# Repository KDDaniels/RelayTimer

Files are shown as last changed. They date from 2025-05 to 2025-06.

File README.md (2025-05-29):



# Relay Timer

Simple timer with a two button interface and LCD screen to show the time remaining. Intended to control a relay but could be used for anything else really.

# Dependencies

I couldn't find it on the PlatformIO library explorer, but this project requires the **[LiquidCrystal_attiny](https://github.com/platisd/ATtiny85-LCD-library/tree/master)** library.

## Features:
- Adjustable time, goes up to 9:59:59 max by default but can be adjusted
- Timer is pausable whenever needed
- Can easily reset the timer while paused or before starting

## Wiring

Intended for an **ATtiny85**, this could definitely be ported to other microcontrollers if needed. Will need slight adjustment due to the direct port register manipulation though.

- NC = No connection
- FB = Function button
- TB = Toggle button
- SCL goes to SCL
- SDA goes to SDA
- Relay goes to a transistor (or straight to a relay if you're feeling bold (don't do that))

```
             ATtiny85
             __   __
 NC <- PB5 =|1 *-* 8|= VCC <- +5v
 FB <- PB3 =|2     7|= PB2 -> SCL
 TB <- PB4 =|3     6|= PB1 -> Relay
GND <- GND =|4_____5|= PB0 -> SDA

```

# Hardware
- ATtiny85 or another microcontroller (will require modification)
- LCD with I<sup>2</sup>C support (I'm using a 1602 screen with a PCF8574 board)
- A relay module
- Two buttons
- A single NPN transistor (I'm using a 2N2222)
- A few resistors (2 4.7kOhm and 5 1kOhm)

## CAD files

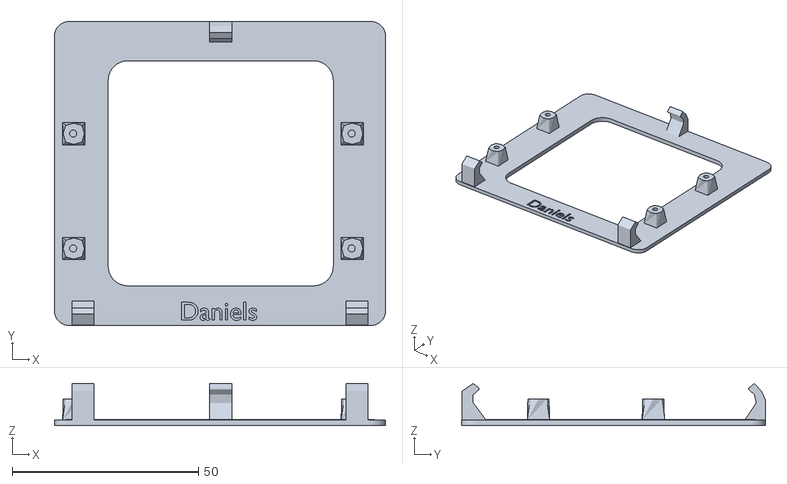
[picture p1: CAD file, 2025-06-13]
assets/RelayTimer_support.stl
88.9 x 81.7 x 11.3

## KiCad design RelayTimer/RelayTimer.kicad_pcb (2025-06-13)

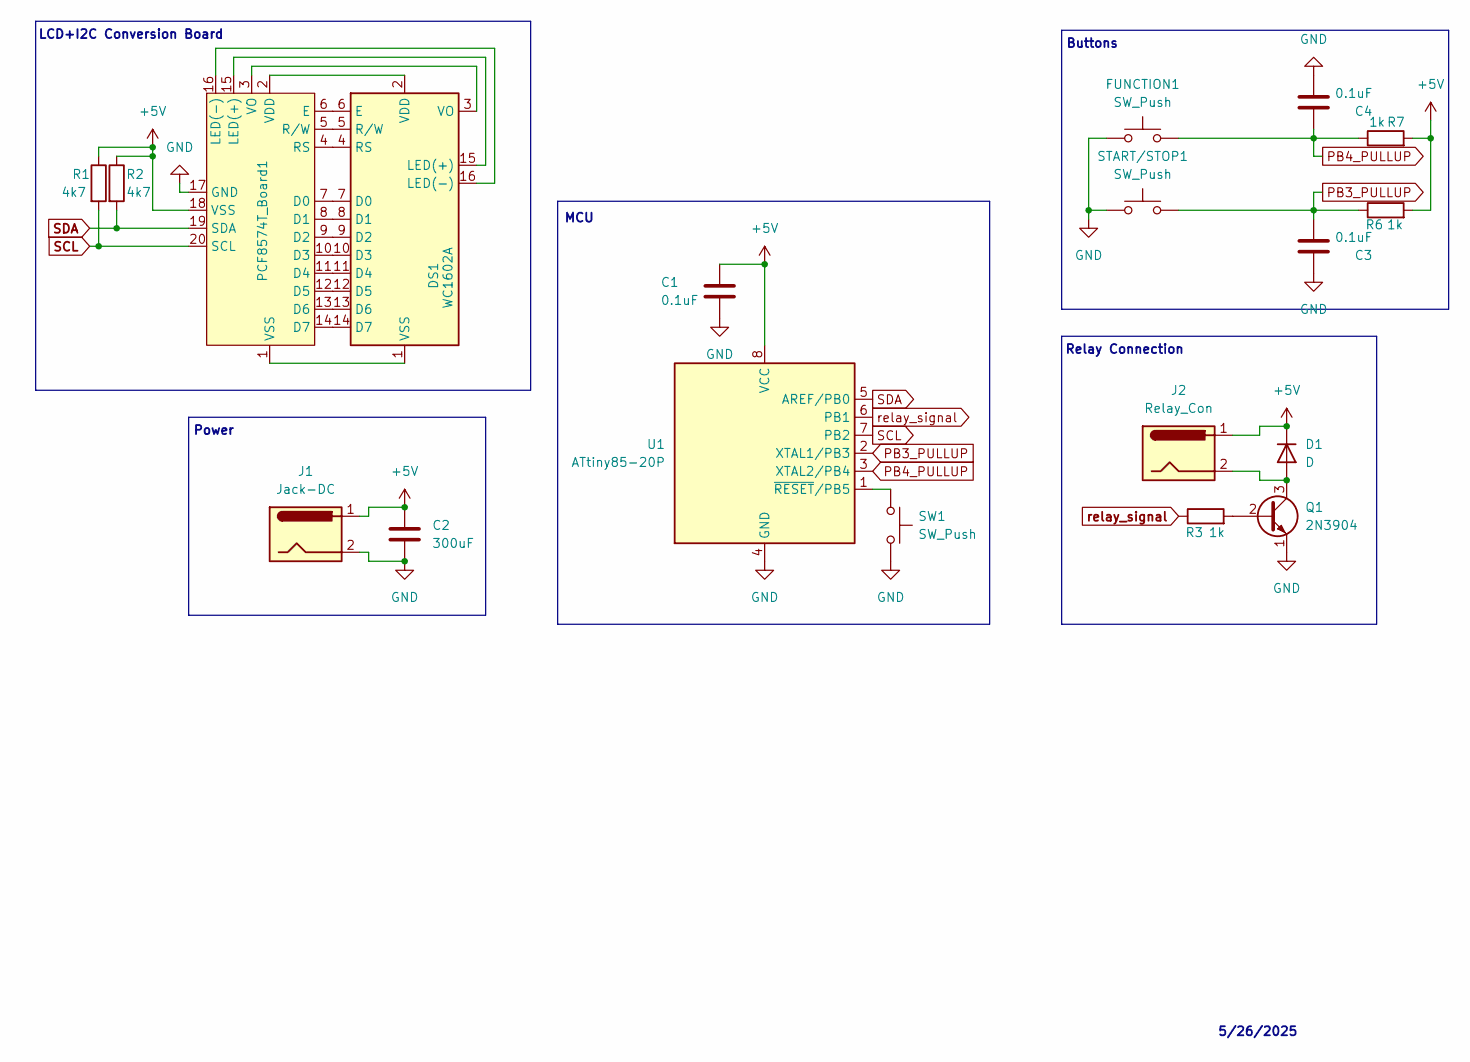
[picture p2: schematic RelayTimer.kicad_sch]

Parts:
C1, C3, C4: 0.1uF; C_Disc_D3.0mm_W1.6mm_P2.50mm
C2: 300uF; C_Radial_D10.0mm_H12.5mm_P5.00mm
D1: D; D_DO-41_SOD81_P2.54mm_Vertical_KathodeUp
DS1: WC1602A
FUNCTION1: SW_Push; SW_PUSH-12mm
J1: Jack-DC; BarrelJack_GCT_DCJ200-10-A_Horizontal
J2: Relay_Con; BarrelJack_GCT_DCJ200-10-A_Horizontal
PCF8574T_Board1: PCF8574T
Q1: 2N3904; TO-92
R1, R2: 4k7; R_Axial_DIN0204_L3.6mm_D1.6mm_P2.54mm_Vertical
R3: 1k; R_Axial_DIN0204_L3.6mm_D1.6mm_P2.54mm_Vertical
R6, R7: 1k; R_Axial_DIN0204_L3.6mm_D1.6mm_P7.62mm_Horizontal
START/STOP1: SW_Push; SW_PUSH-12mm
SW1: SW_Push; SW_PUSH_6mm
U1: ATtiny85-20P; DIP-8_W7.62mm

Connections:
+5V: C1.2, C2.1, D1.1 (K), J1.1, J2.1, PCF8574T_Board1.18 (VSS), R1.1, R2.1, R6.2, R7.2, U1.8 (VCC)
GND: C1.1, C2.2, C3.2, C4.1, FUNCTION1.1, J1.2, PCF8574T_Board1.17 (GND), Q1.1 (E), START/STOP1.1, SW1.2, U1.4 (GND)
unnamed: D1.2 (A), J2.2, Q1.3 (C)
unnamed: DS1.7 (D0), PCF8574T_Board1.7 (D0)
unnamed: DS1.8 (D1), PCF8574T_Board1.8 (D1)
unnamed: DS1.9 (D2), PCF8574T_Board1.9 (D2)
unnamed: DS1.10 (D3), PCF8574T_Board1.10 (D3)
unnamed: DS1.11 (D4), PCF8574T_Board1.11 (D4)
unnamed: DS1.12 (D5), PCF8574T_Board1.12 (D5)
unnamed: DS1.13 (D6), PCF8574T_Board1.13 (D6)
unnamed: DS1.14 (D7), PCF8574T_Board1.14 (D7)
unnamed: DS1.6 (E), PCF8574T_Board1.6 (E)
unnamed: DS1.15 (LED(+)), PCF8574T_Board1.15 (LED(+))
unnamed: DS1.16 (LED(-)), PCF8574T_Board1.16 (LED(-))
unnamed: DS1.4 (RS), PCF8574T_Board1.4 (RS)
unnamed: DS1.5 (R/W), PCF8574T_Board1.5 (R/W)
unnamed: DS1.2 (VDD), PCF8574T_Board1.2 (VDD)
unnamed: DS1.3 (VO), PCF8574T_Board1.3 (VO)
unnamed: DS1.1 (VSS), PCF8574T_Board1.1 (VSS)
unnamed: Q1.2 (B), R3.2
unnamed: SW1.1, U1.1 (~RESET/PB5)
PB3_PULLUP: C3.1, R6.1, START/STOP1.2, U1.2 (XTAL1/PB3)
PB4_PULLUP: C4.2, FUNCTION1.2, R7.1, U1.3 (XTAL2/PB4)
SCL: PCF8574T_Board1.20 (SCL), R1.2, U1.7 (PB2)
SDA: PCF8574T_Board1.19 (SDA), R2.2, U1.5 (AREF/PB0)
relay_signal: R3.1, U1.6 (PB1)

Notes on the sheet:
Relay Connection
Power
5/26/2025
Buttons
MCU
LCD+I2C Conversion Board

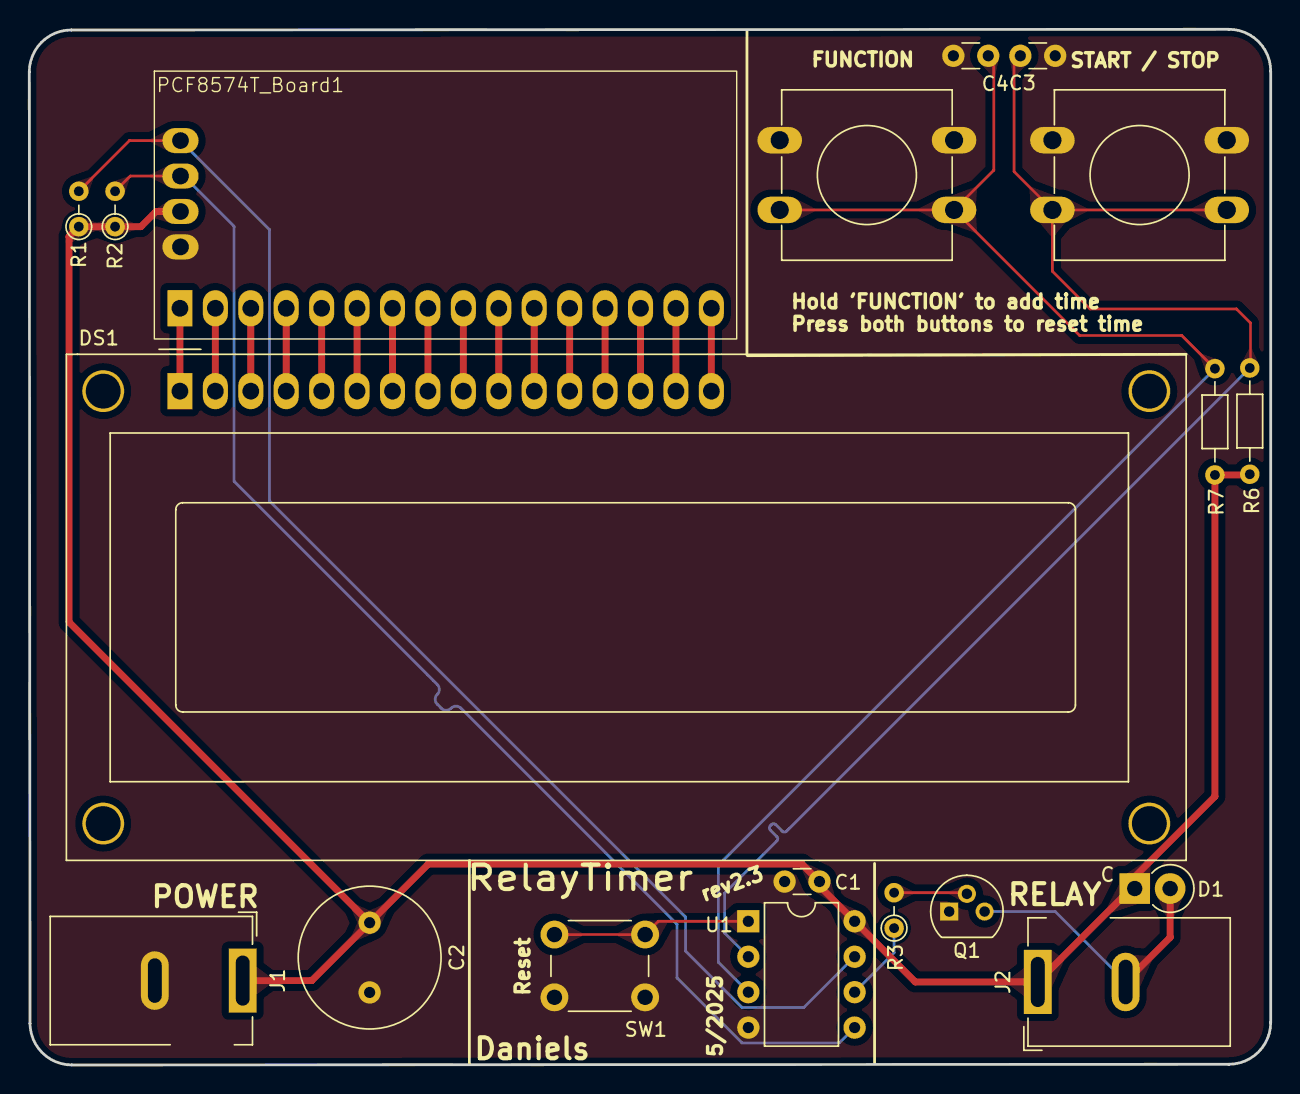
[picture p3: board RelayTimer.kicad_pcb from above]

Board: 2 copper layers, 89.0 x 74.3 mm, 19 parts (0 on the bottom side), 26 nets.

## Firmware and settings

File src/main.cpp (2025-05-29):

/*
RelayTimer is a simple interactive timer to control a relay.
Copyright (C) 2025 Kendall Daniels

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
You should have received a copy of the GNU General Public License
along with this program.  If not, see <https://www.gnu.org/licenses/>.
*/

#include "buttons.h"
#include "display.h"
#include "relay.h"
#include "timer.h"

#define RELAY_PIN PB1
#define FUNC_PIN PB3
#define TOGGLE_PIN PB4

const uint32_t TIMER_INCREMENT = 5000;

bool isRunning = false;

void setup()
{
  SCREEN::init();
  RELAY::init(RELAY_PIN);
  BUTTONS::init(FUNC_PIN, TOGGLE_PIN);

  SCREEN::print("Select time            ", 0, 0);
  SCREEN::print(TIMER::getTimeRemainingFormatted(), 0, 1);
}

void loop()
{
  TIMER::update();
  if (isRunning == true)
  {
    if (!TIMER::paused())
    {
      // Updates the time if not paused
      TIMER::updateTimeRemaining();
      SCREEN::print("Time remaining:     ", 0, 0);
      SCREEN::print(TIMER::getTimeRemainingFormatted(), 0, 1);
    }
    else
    {
      if (BUTTONS::istPinPressed() && BUTTONS::isfPinPressed() && !BUTTONS::isHeld())
      {
        // Resets the timer back to initial state
        TIMER::setTimeRemaining(0);
        SCREEN::print("Select time            ", 0, 0);
        SCREEN::print(TIMER::getTimeRemainingFormatted(), 0, 1);
        isRunning = false;
        TIMER::unpause();
        BUTTONS::holding();
      }
    }

    if (BUTTONS::istPinPressed() && !BUTTONS::isHeld())
    {
      // Pauses the timer
      TIMER::togglePause();
      RELAY::toggle();
      SCREEN::print("Paused            ", 0, 0);
      BUTTONS::holding();
    }
    else if (!BUTTONS::istPinPressed() && BUTTONS::isHeld())
    {
      // Resets toggle button state if not held
      BUTTONS::notHolding();      
    }

    if (TIMER::getTimeRemaining() == 0)
    {
      // Timer hits 0 time remaining, resets to initial state
      RELAY::disable();
      SCREEN::print("Select time            ", 0, 0);
      SCREEN::print(TIMER::getTimeRemainingFormatted(), 0, 1);
      isRunning = false;
    }
  }
  else
  {
    if (!BUTTONS::isHeld())
    {
      if (BUTTONS::isfPinPressed() && !BUTTONS::istPinPressed())
      {
        // If FUNC pin is pressed, add time to timer and display
        TIMER::setTimeRemaining(TIMER::getTimeRemaining() + TIMER_INCREMENT);
        SCREEN::print(TIMER::getTimeRemainingFormatted(), 0, 1);
      }
      else if (BUTTONS::istPinPressed() && BUTTONS::isfPinPressed())
      {
        // If FUNC and TOGGLE are pressed, reset timer to initial state
        TIMER::setTimeRemaining(0);
        SCREEN::print("Select time            ", 0, 0);
        SCREEN::print(TIMER::getTimeRemainingFormatted(), 0, 1);
        BUTTONS::holding();
      }
      else if (BUTTONS::istPinPressed() && TIMER::getTimeRemaining() != 0)
      {
        // If TOGGLE pressed, start timer
        isRunning = true;
        TIMER::unpause();
        RELAY::enable();
        BUTTONS::holding();
      }
    }
    else if (!BUTTONS::istPinPressed() && !BUTTONS::isfPinPressed())
    {
      // Resets button state if neither are pressed
      BUTTONS::notHolding();
    }
  }
}

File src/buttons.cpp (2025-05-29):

#include "buttons.h"

namespace
{
    uint8_t fPin;
    uint8_t tPin;
    bool held = false;
}

namespace BUTTONS
{
    void init(uint8_t funcPin, uint8_t togglePin)
    {
        fPin = funcPin;
        tPin = togglePin;

        // Enable fPin as INPUT and PULLUP
        DDRB &= ~(1 << fPin);
        PORTB |= (1 << fPin);
        
        // Enable tPin as INPUT and PULLUP
        DDRB &= ~(1 << tPin);
        PORTB |= (1 << tPin);
    }

    bool isfPinPressed()
    {
        return !(PINB & (1 << fPin));
    }

    bool istPinPressed()
    {
        return !(PINB & (1 << tPin));
    }

    bool isHeld()
    {
        return held;
    }

    void holding()
    {
        held = true;
    }

    void notHolding()
    {
        held = false;
    }
}

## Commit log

2025-05-28 switched to uploading using Arduino as ISP
2025-05-28 basic relay functions implemented
2025-05-28 added PCB project files
    [RelayTimer.kicad_pcb, RelayTimer.kicad_sch]
2025-05-28 added a couple combo functions
2025-05-29 added some stuff to timer
2025-05-29 added enable/disable functions to relay
2025-05-29 updated folder name
    [RelayTimer.kicad_pcb, RelayTimer.kicad_sch]
2025-05-29 simplified timer functionality
2025-05-29 updated button functionality
2025-05-29 updated relay to use basic port manipulation
2025-05-29 updated buttons to use basic port manipulation
2025-05-29 small update to relay
2025-05-29 added a few button functions
2025-05-29 program functional (without bugs hopefully)
    [main.cpp]
2025-05-30 minor update to KiCad project
    [RelayTimer.kicad_pcb, RelayTimer.kicad_sch]
2025-05-30 added small reset button to schematic
    [RelayTimer.kicad_pcb, RelayTimer.kicad_sch]
2025-05-30 forgot to update the revision number
    [RelayTimer.kicad_pcb]
2025-06-13 fixed small issue and updated board
    [RelayTimer.kicad_pcb, RelayTimer.kicad_sch]
2025-06-13 removed a tiny hidden trace
    [RelayTimer.kicad_pcb]
2025-06-13 added support structure STL
    [RelayTimer_support.stl]

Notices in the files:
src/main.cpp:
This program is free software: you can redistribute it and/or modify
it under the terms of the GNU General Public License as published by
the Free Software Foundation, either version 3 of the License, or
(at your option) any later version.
